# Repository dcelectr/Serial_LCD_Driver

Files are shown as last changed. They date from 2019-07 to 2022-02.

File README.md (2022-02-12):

# Serial_LCD_Driver
LCD Screen Driver with 74HC595.
This uses the 74HC595 to drive LCD displays such as 1602, 1604, 2002, or 2004 with 5V, GND and three Arduino pins (DIN, CS, and CLK). 
Compatible with screens that have 1x16 header.
It is recommended to use a 1x16 male header on the LCD and 1x16 female socket on the Serial_LCD_Driver
The LED (D1) and R2 are optional. You can populate for diagnostics (test the hardware), or connect a panel LED with wires to the Serial_LCD_Driver.
It is recommended to use a resistance value for R2 no lower than 470 Ohms (preferably use 1K with high efficiency LEDs).
The Q1 is used to provide current for the LCD back-light, so that the 74HC595 does not bear the burden to provide the required back-light current (some LCD back-lights draw as much as 200mA). The R1 can be adjusted (1K to 10K) to achieve Q1 saturation for or reduce the current to a desired brightness.
This design has been built and tested with the code provided in this repository. It works! 
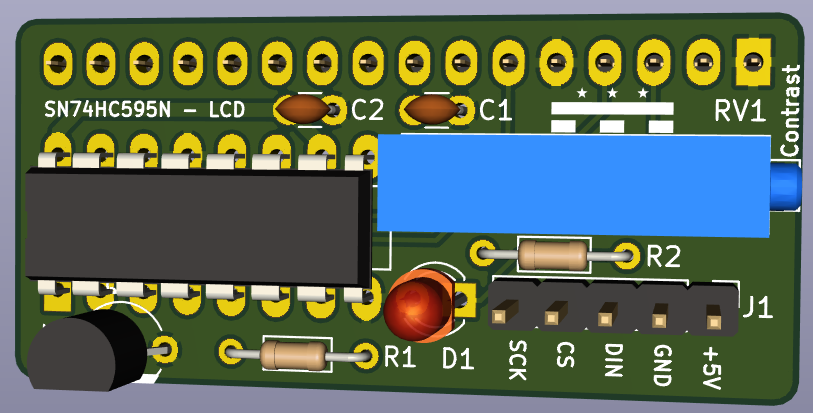
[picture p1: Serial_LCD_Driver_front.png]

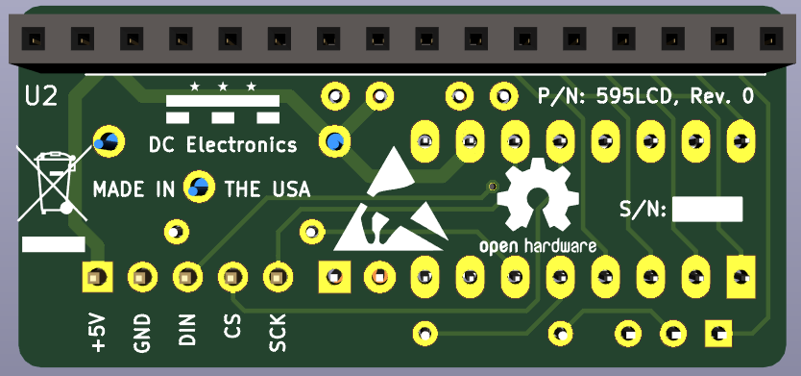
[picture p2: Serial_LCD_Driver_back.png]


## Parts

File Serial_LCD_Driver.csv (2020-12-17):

Reference | Quantity | Value | Part Number | Footprint | Datasheet
C1 | 1 | 100nF | C320C104K5R5TA7317 | Capacitor_THT:C_Disc_D3.0mm_W1.6mm_P2.50mm | ~
C2 | 1 | 10nF | C315C103K5R5TA | Capacitor_THT:C_Disc_D3.0mm_W1.6mm_P2.50mm | ~
D1 | 1 | LED | 3mm LED | LED_THT:LED_D3.0mm | ~
J1 | 1 | Conn_01x05_Male | 1x5 male header | Connector_PinHeader_2.54mm:PinHeader_1x05_P2.54mm_Vertical | ~
Q1 | 1 | BC547 | BC547 | Package_TO_SOT_THT:TO-92_Inline_Wide | http://www.fairchildsemi.com/ds/BC/BC547.pdf
R1 | 1 | 4K7 | 1/8W 4.7 kOhms | Resistor_THT:R_Axial_DIN0204_L3.6mm_D1.6mm_P7.62mm_Horizontal | ~
R2 | 1 | 470 | 1/8W 470 Ohms | Resistor_THT:R_Axial_DIN0204_L3.6mm_D1.6mm_P7.62mm_Horizontal | ~
RV1 | 1 | 10K | 3009P-1-103LF | Potentiometer_THT:Potentiometer_Bourns_3009P_Horizontal | ~
U1 | 1 | 74HC595 | SN74HC595N or 74HCT595N | Package_DIP:DIP-16_W7.62mm_LongPads | http://www.ti.com/lit/ds/symlink/sn74hc595.pdf
U2 | 1 | RC1602A | PPPC161LFBN-RC | Connector_PinSocket_2.54mm:PinSocket_1x16_P2.54mm_Vertical | http://www.raystar-optronics.com/down.php?ProID=18

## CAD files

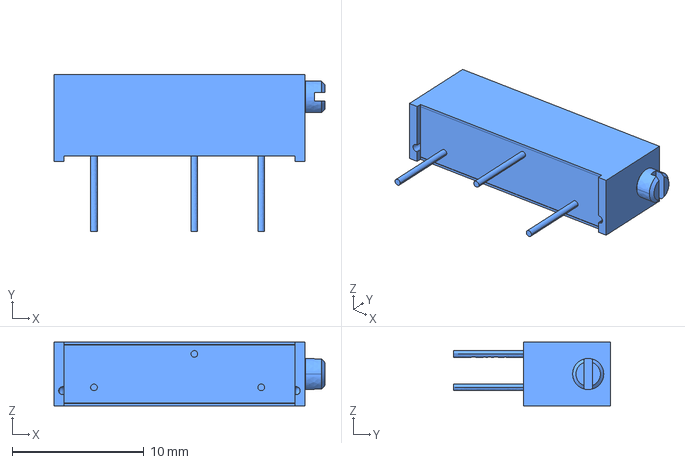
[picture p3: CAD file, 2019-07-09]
3006p-7-103lf.step
20.6 x 11.9 x 4.83 mm

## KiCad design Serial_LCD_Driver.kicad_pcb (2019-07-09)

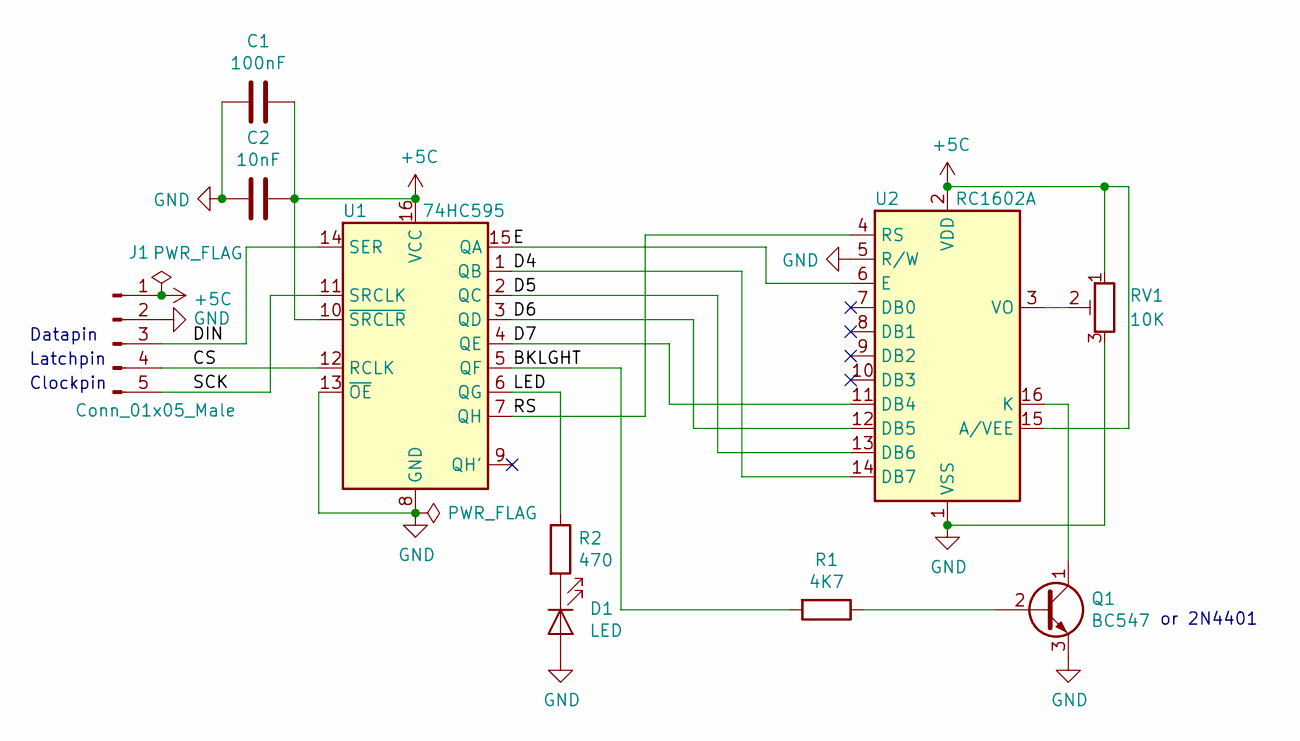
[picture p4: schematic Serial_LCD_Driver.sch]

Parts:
C1: 100nF; C_Disc_D3.0mm_W1.6mm_P2.50mm
C2: 10nF; C_Disc_D3.0mm_W1.6mm_P2.50mm
D1: LED; LED_D3.0mm
J1: Conn_01x05_Male; PinHeader_1x05_P2.54mm_Vertical
Q1: BC547; TO-92_Inline_Wide
R1: 4K7; R_Axial_DIN0204_L3.6mm_D1.6mm_P7.62mm_Horizontal
R2: 470; R_Axial_DIN0204_L3.6mm_D1.6mm_P7.62mm_Horizontal
RV1: 10K; Potentiometer_Bourns_3009P_Horizontal
U1: 74HC595; DIP-16_W7.62mm_LongPads
U2: RC1602A; PinSocket_1x16_P2.54mm_Vertical

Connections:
+5C: C1.1, C2.1, J1.1, RV1.1, U1.10 (~SRCLR), U1.16 (VCC), U2.2 (VDD), U2.15 (A/VEE)
/BKLGHT: R1.2, U1.5 (QF)
/CS: J1.4, U1.12 (RCLK)
/D4: U1.1 (QB), U2.14 (DB7)
/D5: U1.2 (QC), U2.13 (DB6)
/D6: U1.3 (QD), U2.12 (DB5)
/D7: U1.4 (QE), U2.11 (DB4)
/DIN: J1.3, U1.14 (SER)
/E: U1.15 (QA), U2.6 (E)
/LED: R2.1, U1.6 (QG)
/RS: U1.7 (QH), U2.4 (RS)
/SCK: J1.5, U1.11 (SRCLK)
GND: C1.2, C2.2, D1.2 (A), J1.2, Q1.3 (E), RV1.3, U1.8 (GND), U1.13 (~OE), U2.1 (VSS), U2.5 (R/W)
unnamed: D1.1 (K), R2.2
unnamed: Q1.1 (C), U2.16 (K)
unnamed: Q1.2 (B), R1.1
unnamed: RV1.2, U2.3 (VO)

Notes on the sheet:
Datapin
Latchpin
Clockpin
or 2N4401

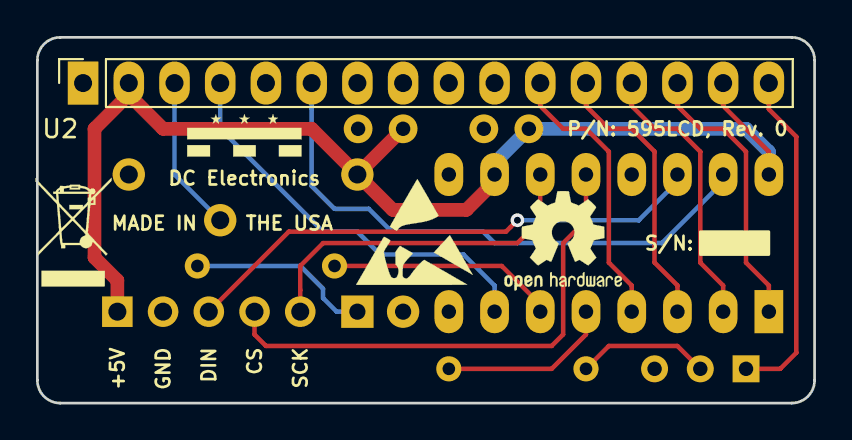
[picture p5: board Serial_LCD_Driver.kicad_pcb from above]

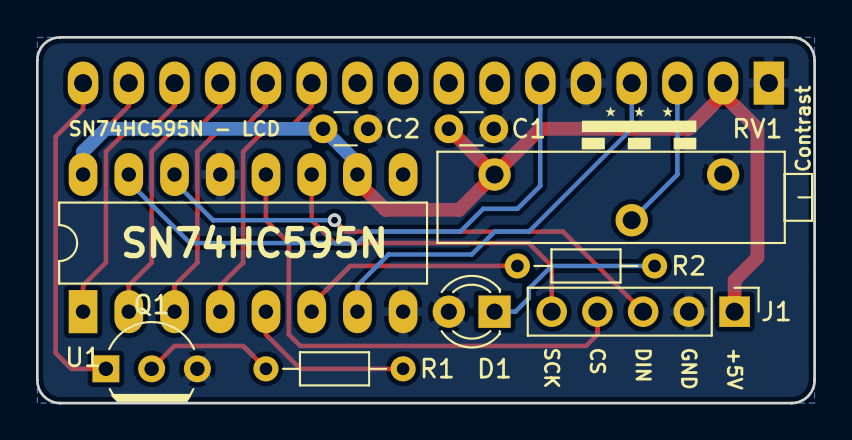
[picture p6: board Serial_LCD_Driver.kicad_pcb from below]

Board: 2 copper layers, 43.2 x 20.3 mm, 10 parts (9 on the bottom side), 17 nets.

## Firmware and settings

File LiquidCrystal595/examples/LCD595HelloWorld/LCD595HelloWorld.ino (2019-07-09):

/* -----------------------------------------------------------------------------------
 * Adaption of the LCD4Bit library shipped with Arduino 22
 * for use with 74C595 shift register adapter board found on:
 * http://www.stephenhobley.com
 
 * Code adaption by Steve Hobley - February 2011

 /*---Shift Register 74HC595---
 * [SR Pin 14 (DS)]    to Arduino pin - Yellow wire [datapin]
 * [SR Pin 12 (ST_CP)] to Arduino pin - Green wire  [latchpin]
 * [SR Pin 11 (SH_CP)] to Arduino pin - White wire  [clockpin]
 * Black wire to Ground
 * Red wire to +5v

 -----Shift Reg to LCD--------
 * SR Pin 15  - ENABLE        10000000
 * SR Pin 1   - D4            00000010 
 * SR Pin 2   - D5	      00000100
 * SR Pin 3   - D6	      00001000
 * SR Pin 4   - D7	      00010000
 * SR Pin 5   - MOSFET / LED1 00100000
 * SR Pin 6   - LED 2         01000000
 * SR Pin 7   - RS            00000001
 *
 * ----------------------------------------------------------------------------------- */
// include the library code:
#include <LiquidCrystal595.h>


// initialize the library with the numbers of the interface pins + the row count
// datapin, latchpin, clockpin, num_lines
LiquidCrystal595 lcd(2,3,4);

void setup() 
{
  lcd.setLED1Pin(HIGH);
  lcd.begin(20,4);

  // Print a message to the LCD.
  lcd.setCursor(0,0);
  lcd.print("This is line 1");
  delay(1000);
  
  lcd.setCursor(0,1);
  lcd.print("This is line 2");
  delay(1000);
  
  lcd.setCursor(16,0);
  lcd.print("This is line 3");
  delay(1000);
  
  lcd.setCursor(16,1);
  lcd.print("This is line 4");
  delay(1000);
  
//  lcd.setCursor(0,3);
//  lcd.print("This is line ");
//  lcd.print(4, BIN); // << Snagged from the Print class
  delay(1000);

}

void loop() 
{
//  lcd.setLED1Pin(LOW);
  lcd.clear();
  delay(500);
//  lcd.setLED1Pin(HIGH);
  lcd.clear();
    lcd.setCursor(0,0);
  lcd.print("Display Blinking");
  delay(500);
}

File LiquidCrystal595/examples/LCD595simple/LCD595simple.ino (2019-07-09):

#include <LiquidCrystal595.h>    // include the library
LiquidCrystal595 lcd(2,3,4);     // datapin, latchpin, clockpin

void setup() {
    
    
    lcd.begin(16,2);             // 16 characters, 2 rows
    lcd.setLED1Pin(HIGH);
    lcd.setLED2Pin(HIGH);
    lcd.clear();
    lcd.setCursor(0,0);
    lcd.print("Hello");
    lcd.setCursor(0,1);
    lcd.print("World");
}

void loop() {
    // not used.
}

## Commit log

2019-07-09 KiCad Files
    [3006p-7-103lf.step, Serial_LCD_Driver.kicad_pcb, Serial_LCD_Driver.sch]
2019-07-09 Arduino library compatible with Serial_LCD_Driver
2020-12-17 Added Bill of Materials CSV file
    [Serial_LCD_Driver.csv]
